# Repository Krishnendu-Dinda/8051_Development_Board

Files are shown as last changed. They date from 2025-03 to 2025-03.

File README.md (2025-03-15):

# 8051_Development_Board
<br>
In my college when I worked in many projects on embedded system using MCU I face many hardware related problems because of create peripherals circuit in breadboard. 
<br>
 For solved this problem I design this 8051 Development board.That is help the student to avoid many hardware related issues due to printed circuit. 
 <br>
 Here in my Development board include one 8-bit output circuit,one 8-bit input circuit, one 8-bit successive approximation A/D converter ,one 16x2 LCD circuit. and also include the programming pins.
<br> 
 It is more helpful if you all are go through the below attached my GitHub link for any advice & review my design.
 <br>

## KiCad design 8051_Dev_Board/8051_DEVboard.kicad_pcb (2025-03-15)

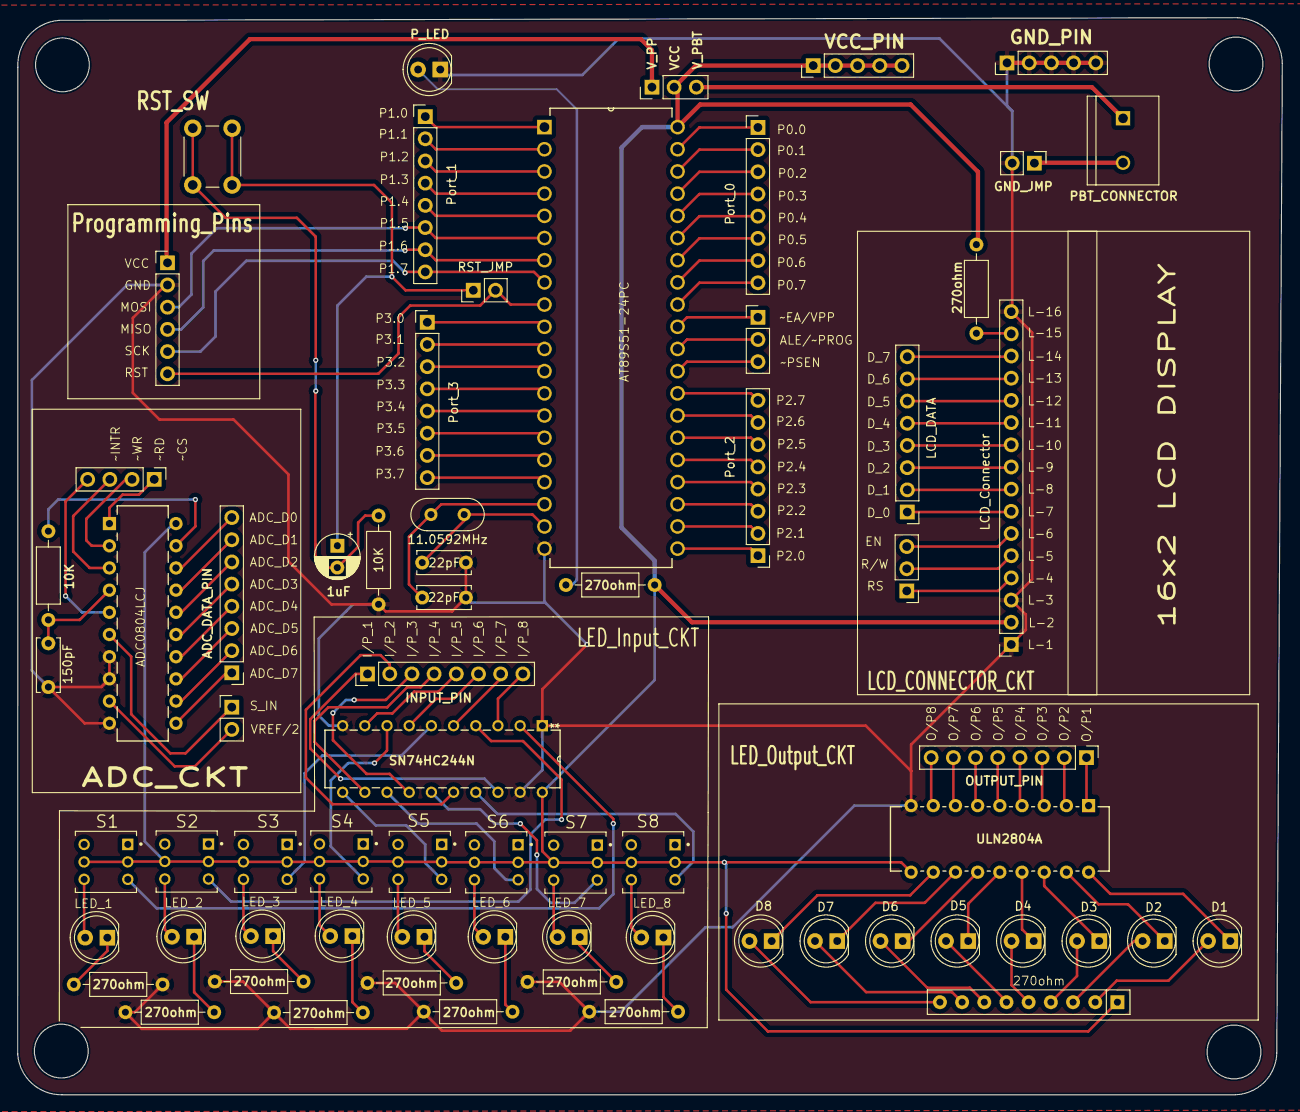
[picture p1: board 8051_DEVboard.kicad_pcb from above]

Board: 2 copper layers, 144.8 x 123.3 mm, 69 parts (1 on the bottom side), 130 nets.

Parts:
1uF1: C_Polarized_US; CP_Radial_D5.0mm_P2.50mm
10K2, 10k1, 270ohm, 270ohm1, 270ohm2, 270ohm3, 270ohm4, 270ohm5, 270ohm6, 270ohm8, 270ohm9, 270ohm10: R_US; R_Axial_DIN0207_L6.3mm_D2.5mm_P10.16mm_Horizontal
ADC_DATA1: Conn_01x08; PinHeader_1x08_P2.54mm_Vertical
C1, C2: 22pF; C_Disc_D6.0mm_W2.5mm_P5.00mm
C3: 150pF; C_Disc_D6.0mm_W2.5mm_P5.00mm
D1, D2, D3, D4, D5, D6, D7, D8, D9, D10, D11, D12, D13, D14, D15, D16, D17: LED; LED_D5.0mm_Clear
GND_JMP1: Conn_01x02; PinHeader_1x02_P2.54mm_Vertical
J1: VCC_PBT_P; PinHeader_1x03_P2.54mm_Vertical
J2: CsRdWrIntr; PinHeader_1x04_P2.54mm_Vertical
J3, J6: Conn_01x02; PinHeader_1x02_P2.54mm_Vertical
J4: LCD_Connection; PinSocket_1x16_P2.54mm_Vertical
J5: Conn_01x03; PinHeader_1x03_P2.54mm_Vertical
J8: GND_PINS; PinHeader_1x05_P2.54mm_Vertical
J9: VCC_PINS; PinHeader_1x05_P2.54mm_Vertical
LCD_DATA1: Conn_01x08; PinHeader_1x08_P2.54mm_Vertical
OUTPUT_LED1, OUTPUT_LED2: Conn_01x08; PinHeader_1x08_P2.54mm_Vertical
PBT_CONNECTOR1: 282837-2; TE_282837-2
Port_0, Port_1, Port_2, Port_3: Conn_01x08; PinHeader_1x08_P2.54mm_Vertical
Programming_Pins1: Conn_01x06; PinHeader_1x06_P2.54mm_Vertical
RN1: 270ohm; R_Array_SIP9
RS_R/W_EN1: Conn_01x03; PinHeader_1x03_P2.54mm_Vertical
S1, S2, S3, S4, S5, S6, S7, S8: TL2230OAF140; DPST_PUSH_SWITCH
SW1: SW_Push; SW_PUSH_6mm
U1: AT89S51-24PC; DIP254P1524X482-40
U2: ULN2804A; ULN2804
U3: SN74HC244N; 74244
U4: ADC0804LCJ; DIP20_300_TEX
Y1: 11.0592MHz; Crystal_HC52-U_Vertical
logo: LOGO

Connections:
/ADC_DB0: ADC_DATA1.8 (Pin_7), U4.18 (DB0)
/ADC_DB1: ADC_DATA1.7 (Pin_6), U4.17 (DB1)
/ADC_DB2: ADC_DATA1.6 (Pin_5), U4.16 (DB2)
/ADC_DB3: ADC_DATA1.5 (Pin_4), U4.15 (DB3)
/ADC_DB4: ADC_DATA1.4 (Pin_3), U4.14 (DB4)
/ADC_DB5: ADC_DATA1.3 (Pin_2), U4.13 (DB5)
/ADC_DB6: ADC_DATA1.2 (Pin_1), U4.12 (DB6)
/ADC_DB7: ADC_DATA1.1 (Pin_0), U4.11 (DB7)
/CLKIN: 10K2.2, C3.1, U4.4 (CLKIN)
/CLKR: 10K2.1, U4.19 (CLKR)
/INT0: Port_3.3 (Pin_2), U1.12 ((INT0)_P3.2)
/INT1: Port_3.4 (Pin_3), U1.13 ((INT1)_P3.3)
/MISO: Port_1.7 (Pin_6), Programming_Pins1.4, U1.7 ((MISO)_P1.6)
/MOSI: Port_1.6 (Pin_5), Programming_Pins1.3, U1.6 ((MOSI)_P1.5)
/PBT_GND: GND_JMP1.1, PBT_CONNECTOR1.2
/PBT_VCC: J1.3, PBT_CONNECTOR1.1
/P_VCC: J1.1, Programming_Pins1.1
/RD: Port_3.8 (Pin_7), U1.17 ((RD)_P3.7)
/RST: J3.2, Programming_Pins1.6, U1.9 (RST)
/RXD: Port_3.1 (Pin_0), U1.10 ((RXD)_P3.0)
/SCK: Port_1.8 (Pin_7), Programming_Pins1.5, U1.8 ((SCK)_P1.7)
/SENSOR_IN: J6.1, U4.6 (VIN+)
/SW1_LED: D10.2 (A), S1.6
/SW2_LED: D11.2 (A), S2.6
/SW3_LED: D12.2 (A), S3.6
/SW4_LED: D14.2 (A), S4.6
/SW5_LED: D17.2 (A), S5.6
/SW6_LED: D16.2 (A), S6.6
/SW7_LED: D13.2 (A), S7.6
/SW8_LED: D15.2 (A), S8.6
/SW_1: S1.3, U3.2 (1A1)
/SW_1_out: OUTPUT_LED2.1 (Pin_0), U3.18 (1Y1)
/SW_2: S2.3, U3.4 (1A2)
/SW_2_out: OUTPUT_LED2.2 (Pin_1), U3.16 (1Y2)
/SW_3: S3.3, U3.6 (1A3)
/SW_3_out: OUTPUT_LED2.3 (Pin_2), U3.14 (1Y3)
/SW_4: S4.3, U3.8 (1A4)
/SW_4_out: OUTPUT_LED2.4 (Pin_3), U3.12 (1Y4)
/SW_5: S5.3, U3.11 (2A1)
/SW_5_out: OUTPUT_LED2.5 (Pin_4), U3.9 (2Y1)
/SW_6: S6.3, U3.13 (2A2)
/SW_6_out: OUTPUT_LED2.6 (Pin_5), U3.7 (2Y2)
/SW_7: S7.3, U3.15 (2A3)
/SW_7_out: OUTPUT_LED2.7 (Pin_6), U3.5 (2Y3)
/SW_8: S8.3, U3.17 (2A4)
/SW_8_out: OUTPUT_LED2.8 (Pin_7), U3.3 (2Y4)
/T0: Port_3.5 (Pin_4), U1.14 ((T0)_P3.4)
/T1: Port_3.6 (Pin_5), U1.15 ((T1)_P3.5)
/TXD: Port_3.2 (Pin_1), U1.11 ((TXD)_P3.1)
/VCC: 270ohm1.1, 270ohm2.1, J1.2, J4.2, J9.1, J9.2, J9.3, J9.4, J9.5, RN1.1 (common), S1.2, S1.5, S2.2, S2.5, S3.2, S3.5, S4.2, S4.5, S5.2, S5.5, S6.2, S6.5, S7.2, S7.5, S8.2, S8.5, U1.40 (VCC), U2.10 (COM), U3.20 (VCC), U4.20 (VCC)
/VREF/2: J6.2, U4.9 (VREF/2)
/WR: Port_3.7 (Pin_6), U1.16 ((WR)_P3.6)
/~CS: J2.1, U4.1 (~CS)
/~INTR: J2.4, U4.5 (~INTR)
/~RD: J2.2, U4.2 (~RD)
/~WR: J2.3, U4.3 (~WR)
GND: 10k1.2, 270ohm.1, 270ohm3.1, 270ohm4.1, 270ohm5.1, 270ohm6.1, 270ohm8.1, 270ohm9.1, 270ohm10.1, C1.1, C2.1, C3.2, D9.1 (K), GND_JMP1.2, J4.1, J4.3, J4.16, J8.1, J8.2, J8.3, J8.4, J8.5, Programming_Pins1.2, U1.20 (GND), U2.9 (GND), U3.1 (*1OE), U3.10 (GND), U3.19 (*2OE), U4.7 (VIN-), U4.8 (AGND), U4.10 (DGND)
unnamed: 1uF1.2, 10k1.1, SW1.1
unnamed: D1.2 (A), RN1.2 (R1)
unnamed: D1.1 (K), U2.18 (O1)
unnamed: D2.2 (A), RN1.3 (R2)
unnamed: D2.1 (K), U2.17 (O2)
unnamed: D3.2 (A), RN1.4 (R3)
unnamed: D3.1 (K), U2.16 (O3)
unnamed: D4.2 (A), RN1.5 (R4)
unnamed: D4.1 (K), U2.15 (O4)
unnamed: D5.2 (A), RN1.6 (R5)
unnamed: D5.1 (K), U2.14 (O5)
unnamed: D6.2 (A), RN1.7 (R6)
unnamed: D6.1 (K), U2.13 (O6)
unnamed: D7.2 (A), RN1.8 (R7)
unnamed: D7.1 (K), U2.12 (O7)
unnamed: D8.2 (A), RN1.9 (R8)
unnamed: D8.1 (K), U2.11 (O8)
unnamed: 270ohm2.2, D9.2 (A)
unnamed: 270ohm3.2, D10.1 (K)
unnamed: 270ohm4.2, D11.1 (K)
unnamed: 270ohm5.2, D12.1 (K)
unnamed: 270ohm8.2, D13.1 (K)
unnamed: 270ohm6.2, D14.1 (K)
unnamed: 270ohm.2, D15.1 (K)
unnamed: 270ohm9.2, D16.1 (K)
unnamed: 270ohm10.2, D17.1 (K)
unnamed: 1uF1.1, J3.1, SW1.2
unnamed: J4.4, RS_R/W_EN1.1
unnamed: J4.5, RS_R/W_EN1.2
unnamed: J4.6, RS_R/W_EN1.3
unnamed: J4.7, LCD_DATA1.1 (Pin_0)
unnamed: J4.8, LCD_DATA1.2 (Pin_1)
unnamed: J4.9, LCD_DATA1.3 (Pin_2)
unnamed: J4.10, LCD_DATA1.4 (Pin_3)
unnamed: J4.11, LCD_DATA1.5 (Pin_4)
unnamed: J4.12, LCD_DATA1.6 (Pin_5)
unnamed: J4.13, LCD_DATA1.7 (Pin_6)
unnamed: J4.14, LCD_DATA1.8 (Pin_7)
unnamed: 270ohm1.2, J4.15
unnamed: J5.1, U1.31 (~EA/VPP)
unnamed: J5.2, U1.30 (ALE/~PROG)
unnamed: J5.3, U1.29 (~PSEN)
unnamed: OUTPUT_LED1.1 (Pin_0), U2.1 (I1)
unnamed: OUTPUT_LED1.2 (Pin_1), U2.2 (I2)
unnamed: OUTPUT_LED1.3 (Pin_2), U2.3 (I3)
unnamed: OUTPUT_LED1.4 (Pin_3), U2.4 (I4)
unnamed: OUTPUT_LED1.5 (Pin_4), U2.5 (I5)
unnamed: OUTPUT_LED1.6 (Pin_5), U2.6 (I6)
unnamed: OUTPUT_LED1.7 (Pin_6), U2.7 (I7)
unnamed: OUTPUT_LED1.8 (Pin_7), U2.8 (I8)
unnamed: Port_0.1 (Pin_0), U1.39 (P0.0_(AD0))
unnamed: Port_0.2 (Pin_1), U1.38 (P0.1_(AD1))
unnamed: Port_0.3 (Pin_2), U1.37 (P0.2_(AD2))
unnamed: Port_0.4 (Pin_3), U1.36 (P0.3_(AD3))
unnamed: Port_0.5 (Pin_4), U1.35 (P0.4_(AD4))
unnamed: Port_0.6 (Pin_5), U1.34 (P0.5_(AD5))
unnamed: Port_0.7 (Pin_6), U1.33 (P0.6_(AD6))
unnamed: Port_0.8 (Pin_7), U1.32 (P0.7_(AD7))
unnamed: Port_1.1 (Pin_0), U1.1 ((T2)_P1.0)
unnamed: Port_1.2 (Pin_1), U1.2 ((T2_EX)_P1.1)
unnamed: Port_1.3 (Pin_2), U1.3 (P1.2)
unnamed: Port_1.4 (Pin_3), U1.4 (P1.3)
unnamed: Port_1.5 (Pin_4), U1.5 (P1.4)
unnamed: Port_2.1 (Pin_0), U1.21 (P2.0_(A8))
unnamed: Port_2.2 (Pin_1), U1.22 (P2.1_(A9))
unnamed: Port_2.3 (Pin_2), U1.23 (P2.2_(A10))
unnamed: Port_2.4 (Pin_3), U1.24 (P2.3_(A11))
unnamed: Port_2.5 (Pin_4), U1.25 (P2.4_(A12))
unnamed: Port_2.6 (Pin_5), U1.26 (P2.5_(A13))
unnamed: Port_2.7 (Pin_6), U1.27 (P2.6_(A14))
unnamed: Port_2.8 (Pin_7), U1.28 (P2.7_(A15))
unnamed: C2.2, U1.19 (XTAL1), Y1.2
unnamed: C1.2, U1.18 (XTAL2), Y1.1
